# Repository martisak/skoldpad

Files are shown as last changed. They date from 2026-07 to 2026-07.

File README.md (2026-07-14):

<p align="center">
  <picture>
    <source media="(prefers-color-scheme: dark)" srcset="./images/header-white.svg">
    <source media="(prefers-color-scheme: light)" srcset="./images/header-black.svg">
    Sköldpad logo
  </picture>
</p>

A split, columnar-staggered keyboard built around a
[nice!nano](https://nicekeyboards.com/nice-nano/) MCU with a rotary encoder, laid out with
[ergogen](https://github.com/ergogen/ergogen) and routed in KiCad. It's based on/inspired by
[josukey](https://github.com/Narkoleptika/josukey) (MIT licensed), an ergogen-based Corne clone.

Firmware ([ZMK](https://zmk.dev/), with a custom keymap tuned for Swedish input and coding
symbols) lives in its own repo: **[martisak/zmk-config](https://github.com/martisak/zmk-config)**.

## Renders

<p align="center">
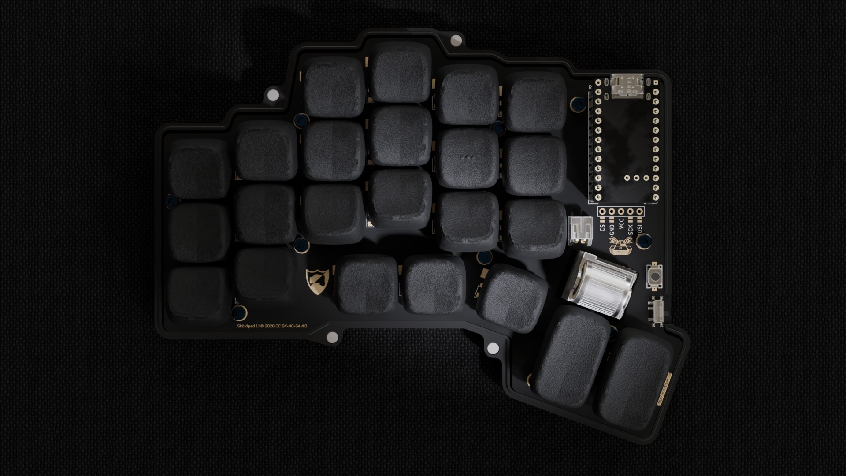
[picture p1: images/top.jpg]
    
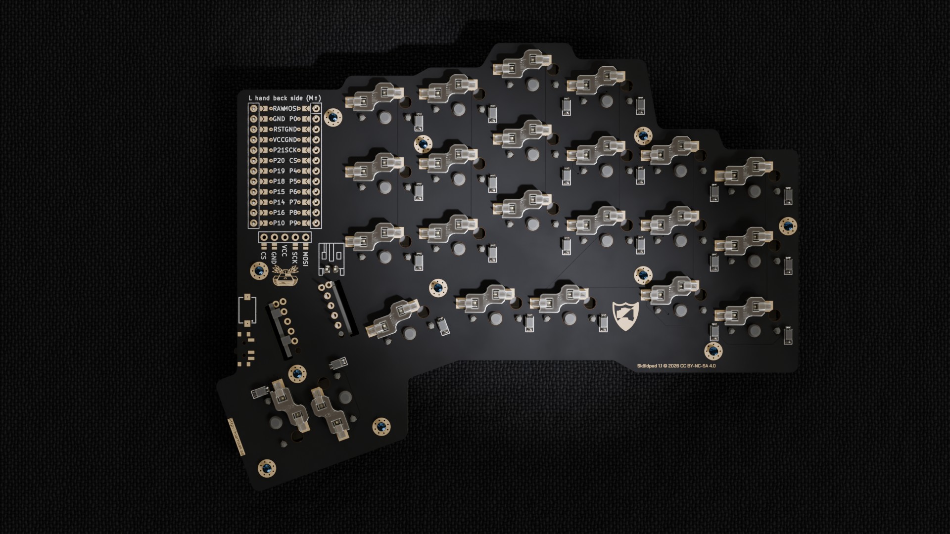
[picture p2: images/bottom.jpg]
    
</p>
<p align="center">
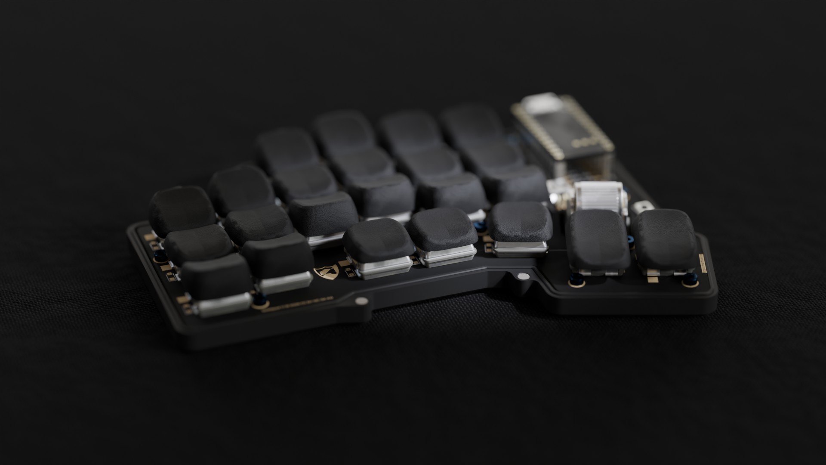
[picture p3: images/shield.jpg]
    
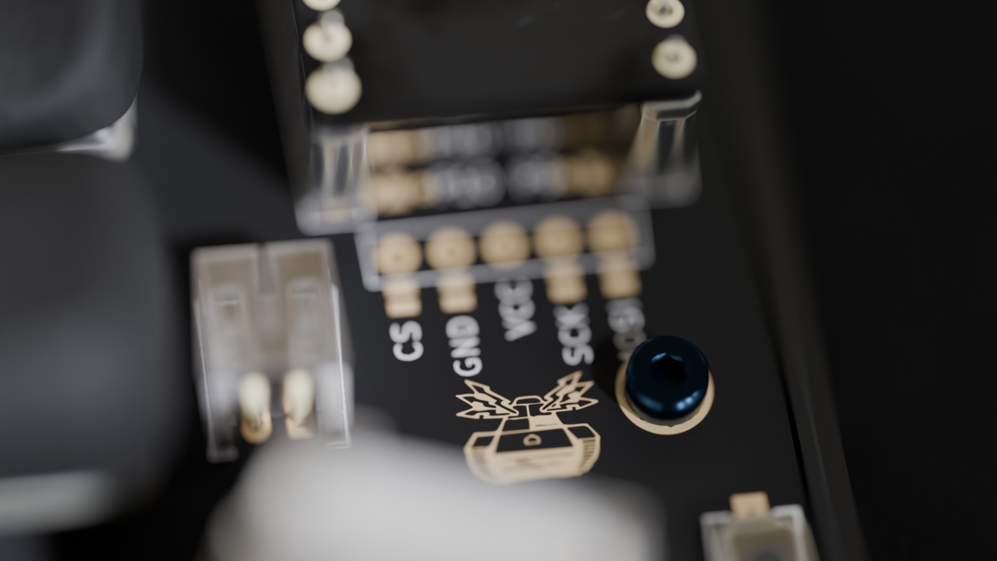
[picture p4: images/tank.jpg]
    
</p>

## Prerequisites

* Node
* KiCad (to open/edit the PCB)

## Getting Started

```bash
git clone https://github.com/martisak/skoldpad.git
cd skoldpad
npm i
```

## Ergogen

The layout lives in `ergogen/config.yaml`.

### Build

Runs Ergogen and builds all of the output files (outlines, case, PCB skeleton) into `ergogen/output`.

```bash
npm run ergogen:build
```

### Watch

Watches `config.yaml` and the `footprints` directory and re-runs the build on changes.

```bash
npm run ergogen:watch
```

## KiCad

The hand-routed PCB lives at [`ergogen/kicad/skoldpad.kicad_pcb`](./ergogen/kicad/skoldpad.kicad_pcb)
(along with the schematic, 3D step model, and the custom `Skoldpad.pretty` footprint library it
depends on) — open `ergogen/kicad/skoldpad.kicad_pro` in KiCad.

<p align="center">
  <picture>
    <source media="(prefers-color-scheme: dark)" srcset="./images/schematic-dark.svg">
    <source media="(prefers-color-scheme: light)" srcset="./images/schematic-light.svg">
    Sköldpad PCB layout
  </picture>
</p>

Regenerate these from the routed board with `make schematics` (requires `kicad-cli` and Python 3
on `PATH`); see the [`Makefile`](./Makefile).

## Firmware

Firmware and keymap are maintained separately at
[martisak/zmk-config](https://github.com/martisak/zmk-config):

```bash
git clone git@github.com:martisak/zmk-config.git
```

It's a [nice!nano](https://nicekeyboards.com/nice-nano/) ZMK build with its own keymap (not
based on Miryoku), tuned for the macOS Swedish layout — base layer plus NUM, FUNC, and
directional layers. Builds run in GitHub Actions on every push; grab the `.uf2` artifacts from
the latest successful run.

The PCB footprints support a [nice!view](https://nicekeyboards.com/nice-view) display — this
should work but hasn't been tested yet.

## Case

<p align="center">
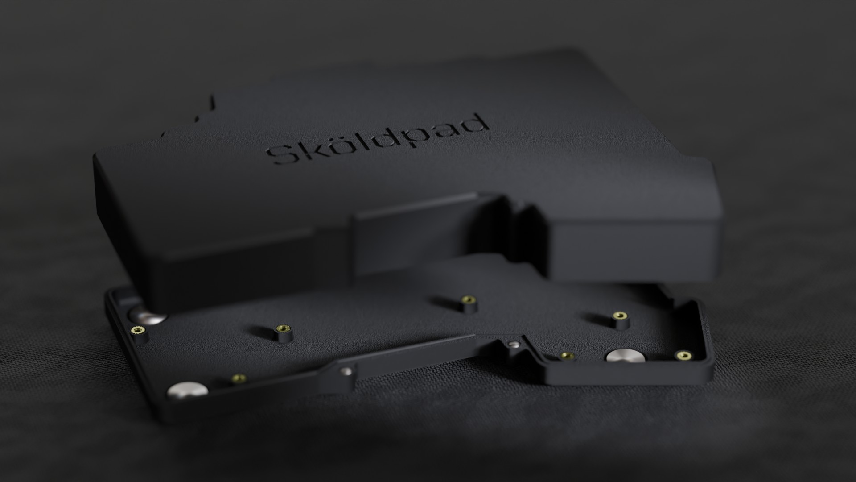
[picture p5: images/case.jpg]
    
</p>

The case is designed in [Shapr3D](https://app.shapr3d.com/p/ba8f4a1e-6f99-4bed-8f1e-6df41bfcee0b)
(viewable in 3D at that link) and 3D printed. STL files for both halves (top and bottom shells)
are in [`case/`](./case):

* [`case/left.stl`](./case/left.stl) / [`case/left_top.stl`](./case/left_top.stl)
* [`case/right.stl`](./case/right.stl) / [`case/right_top.stl`](./case/right_top.stl)

## Bill of Materials

Quantities below are **per half**; this design is one hand's PCB, fabricated twice (one
normal, one mirrored) for a complete pair — double everything for a full two-hand build.

**This PCB is Choc v1 (PG1350) only.** The switch footprint's center hole and stabilizer-leg
positions don't match Choc v2 or MX, so neither is a drop-in substitution — see Future Work.

| Part | Qty/half | Notes |
|---|---:|---|
| [nice!nano](https://nicekeyboards.com/nice-nano/) | 1 | MCU, one per half (each half is an independent BLE unit) |
| [nice!view](https://nicekeyboards.com/nice-view) | 1 | Display — **untested**, see Known Issues; optional |
| Panasonic EVQWGD001 rotary encoder | 1 | ⚠️ Discontinued by Panasonic — check old-stock listings (e.g. [Jotrin](https://www.jotrin.com/product/parts/EVQWGD001)) or plan to substitute a pin-compatible EVQW-series encoder |
| Kailh Choc v1 switch | 23 | See Future Work — v2 is the recommended switch going forward |
| Kailh PG1350 hotswap socket | 23 | Choc v1 hotswap socket, e.g. [Chosfox](https://chosfox.com/products/kailh-choc-switch-1350-hot-swap-sockets) |
| SOD-123W diode (e.g. 1N4148W) | 23 | Standard keyboard-matrix switching diode |
| JST PH 2-pin connector (S2B-PH-K, 2.0mm) | 1 | Battery connector |
| LiPo battery (JST PH 2-pin) | 1 | Capacity not specified by the design — pick to fit the case |
| Kailh PCM12 SPDT slide switch | 1 | Power on/off |
| Würth WS-TASV SMT tactile switch ([434121025816](https://www.digikey.com/en/products/detail/w%C3%BCrth-elektronik/434121025816/5209078)) | 1 | Reset button |
| M2 screws + threaded inserts/standoffs | 11 sets | One per mounting point in `config.yaml` (`screw_*` positions) |
| 1u keycap (Choc profile) | 21 | |
| 1.5u keycap (Choc profile) | 2 | Thumb keys — see Known Issues re: rotation |

Not in the PCB itself but needed to finish a build: the 3D-printed case (see Case section
above) and a filament of your choice.

## Known Issues

* The two thumb keys should be rotated to accept a 1.5u keycap, as shown in the renders.
* nice!view support is untested — should work per the footprint, but not confirmed on hardware.
* The case's screw posts are thin and prone to cracking when installing the threaded inserts
  (see Bill of Materials — M2 screws + threaded inserts/standoffs); consider thickening the
  posts in the Shapr3D model or heat-setting inserts more carefully.

## Future Work

* Move to Choc v2 switches — currently on v1, which has a smaller center post than v2.
* Test compatibility with full-size MX switches.
* Test nice!view once one arrives (currently on order).
* Update the BOM's rotary encoder — the specified Panasonic EVQWGD001 is discontinued;
  find and validate a pin-compatible replacement.
* Consider per-key LEDs instead of underglow — underglow would need a transparent case,
  which the current 3D-printed design isn't.

## License

Code (footprint generator scripts, build tooling) is [MIT](./LICENSE). The
hardware design (PCB, schematic, case, and ergogen layout) is
[CC BY-NC-SA 4.0](./LICENSE-HARDWARE), matching the license of the nice!nano
and nice!view footprints it incorporates (see Thanks below).

## Thanks

* <a href="https://github.com/ergogen/ergogen" target="_blank">Ergogen</a>
* <a href="https://discord.gg/nbKcAZB" target="_blank">Absolem Club Discord</a>
* <a href="https://github.com/infused-kim/kb_ergogen_fp" target="_blank">@infused-kim</a>
  for the original nice!nano and nice!view footprints, and
  <a href="https://github.com/ceoloide/ergogen-footprints" target="_blank">@ceoloide</a>
  for maintaining and upgrading them to KiCad 8 (both CC BY-NC-SA 4.0)
* <a href="https://github.com/tsteffek/Ergogen-V4-Migration-Guide" target="_blank">V4 Migration Guide</a>
* <a href="https://gitlab.com/Audijo/keyboard" target="_blank">Claw</a>
* <a href="https://github.com/MrCarney/mrkeyboard" target="_blank">MrKeyboard</a>
* <a href="https://github.com/foostan/crkbd" target="_blank">Corne keyboard</a>
* <a href="https://www.youtube.com/watch?v=dg2TT1OJlQs" target="_blank">Ben Vallack</a>
* <a href="https://github.com/zmkfirmware/zmk" target="_blank">ZMK</a>
* <a href="https://github.com/Narkoleptika/josukey" target="_blank">josukey</a> — the base this board started from
* <a href="https://sv.wikipedia.org/wiki/V%C3%A4sterg%C3%B6tlands_landskapsvapen" target="_blank">Västergötlands landskapsvapen</a> — inspiration for the logo
* <a href="https://fonts.google.com/specimen/Chakra+Petch" target="_blank">Chakra Petch</a> — typeface used for PCB text and case engraving

## AI Disclosure

Claude (Anthropic) assisted with README and documentation polish — drafting and formatting
text (including the BOM table and general presentation of this repo) from the author's own
notes and decisions. The design, PCB, firmware, fabrication work, and content substance
(including Known Issues and Future Work) are the author's own.

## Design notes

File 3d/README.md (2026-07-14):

# 3D models

Referenced by `(model ...)` entries in `ergogen/kicad/skoldpad.kicad_pcb` via
`${KIPRJMOD}/../../3d/`. Ergogen's footprint generators don't attach these (the
choc switch/socket/keycap models are per-instance overrides added directly in
the board file; `mcu_nice_nano.js` supports a `mcu_3dmodel_filename` param but
it isn't set in `config.yaml`, so this MCU model is also a per-instance override).

| File | Part | Source | License |
|---|---|---|---|
| `SW_Kailh_Choc_V1.stp` | Kailh Choc v1 (PG1350) switch | [kiswitch/kiswitch](https://github.com/kiswitch/kiswitch) | MIT / CC-BY-SA (dual) |
| `SW_Hotswap_Kailh_Choc_v1.stp` | Kailh Choc v1 hotswap socket | [kiswitch/kiswitch](https://github.com/kiswitch/kiswitch) | MIT / CC-BY-SA (dual) |
| `MBK-1u.step` | MBK profile 1u keycap | [namnlos-io/choc_keycaps](https://github.com/namnlos-io/choc_keycaps), MBK folder, by Max Burger | CC BY-NC 4.0 |
| `MBK_Keycap_-_1.5u.step` | MBK profile 1.5u keycap | [namnlos-io/choc_keycaps](https://github.com/namnlos-io/choc_keycaps), MBK folder, by Max Burger | CC BY-NC 4.0 |
| `nice!nano v2.step` | nice!nano v2 MCU | [GrabCAD: nice!nano v2](https://grabcad.com/library/nice-nano-v2-1) | check GrabCAD page for terms before redistributing |

The choc/hotswap/keycap filenames match what the hand-routed board already
referenced (as absolute paths on another machine, `/Users/eisamar/devel/...`)
before this fix — same model family, just relocated under the repo and made
portable via `${KIPRJMOD}`.

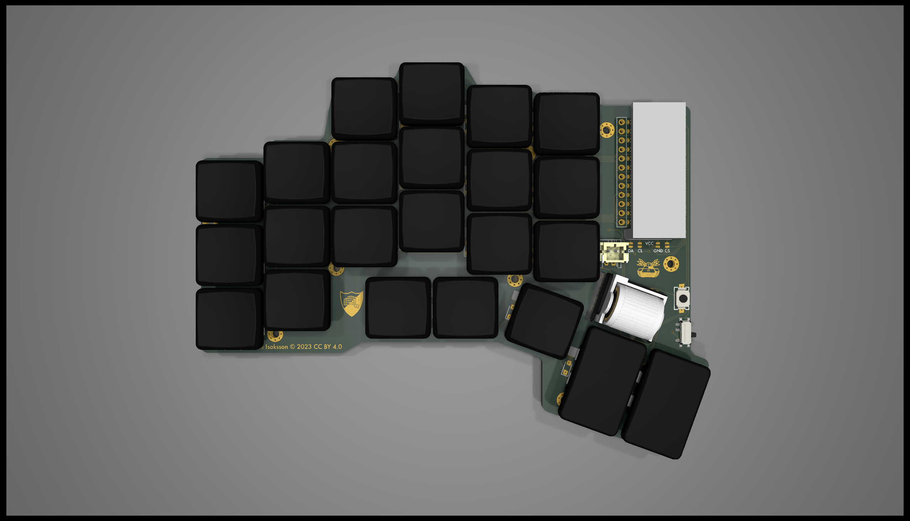
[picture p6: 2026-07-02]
images/top.png

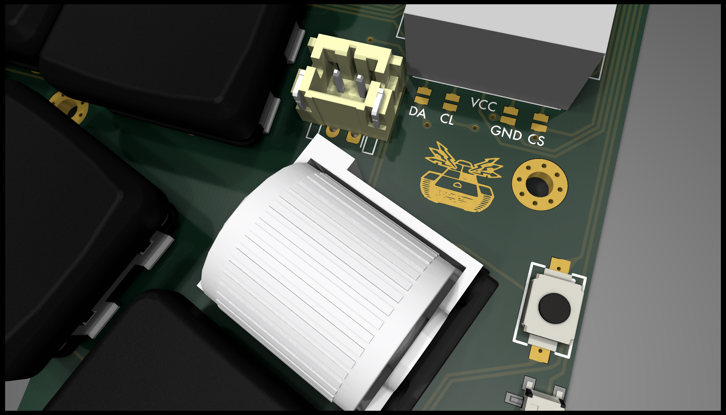
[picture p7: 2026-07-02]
images/tank.png

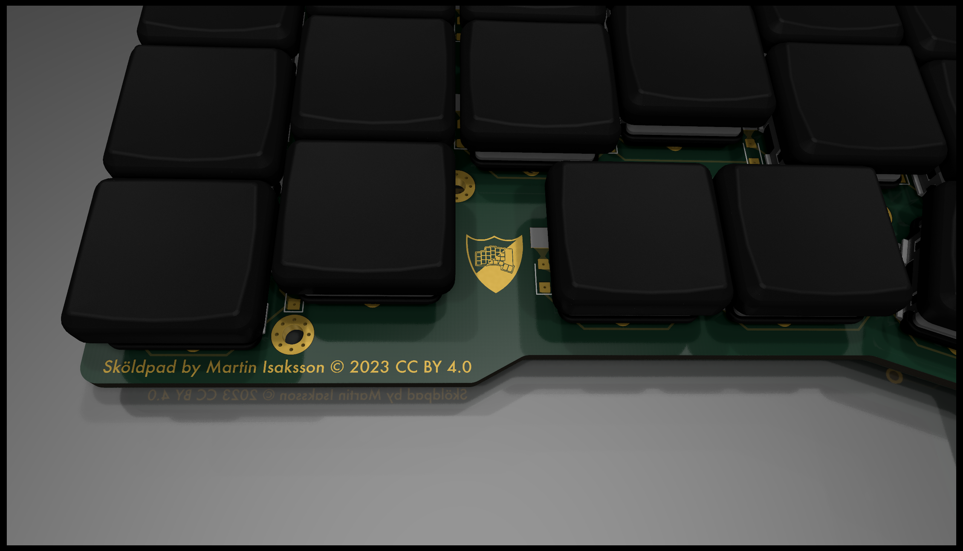
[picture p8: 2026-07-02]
images/shield.png

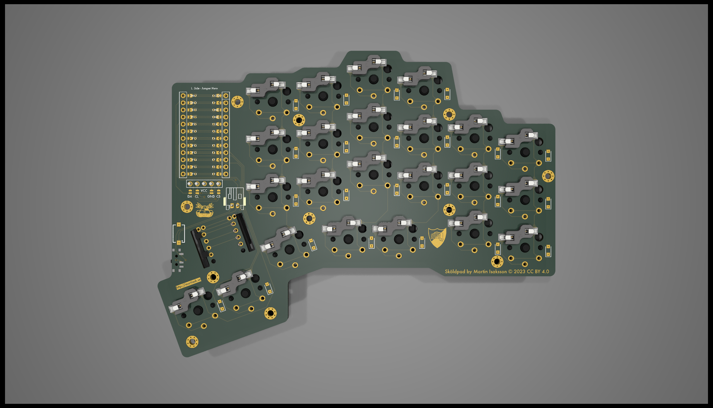
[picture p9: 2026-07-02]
images/bottom.png

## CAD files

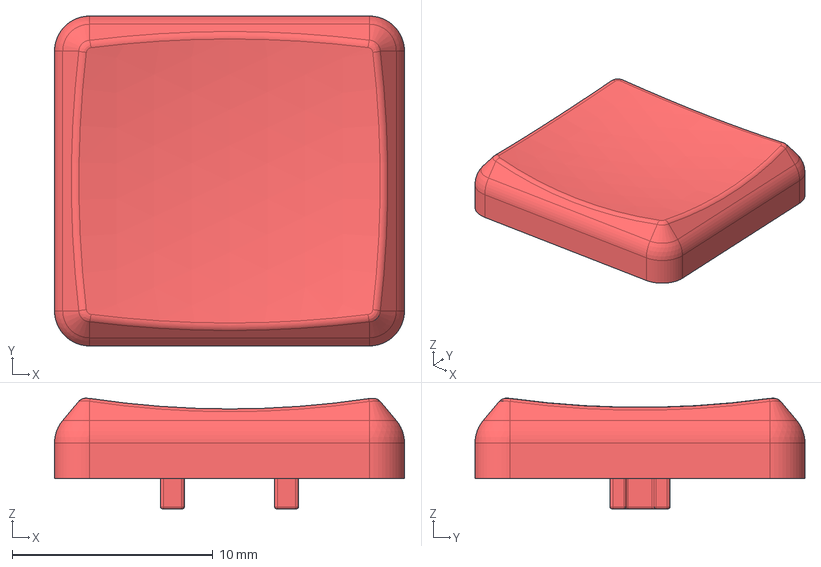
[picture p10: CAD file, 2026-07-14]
3d/MBK-1u.step
17.4 x 16.4 x 5.52 mm

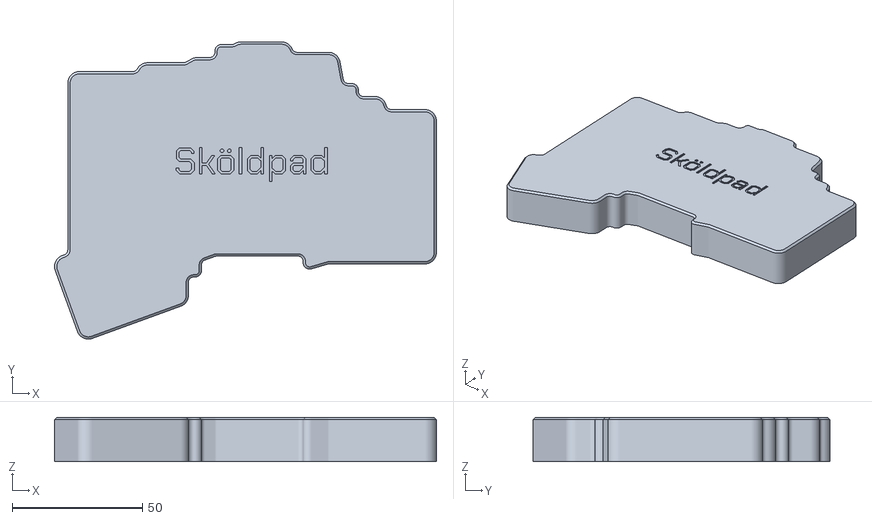
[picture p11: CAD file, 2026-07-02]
case/right_top.stl
146.9 x 114.3 x 17.0

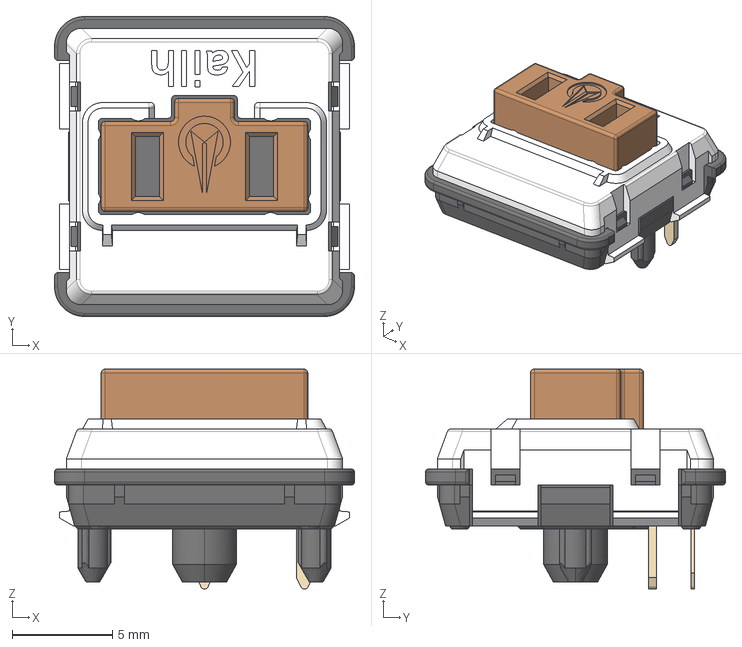
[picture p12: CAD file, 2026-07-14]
3d/SW_Kailh_Choc_V1.stp
15.0 x 15.0 x 11.0 mm

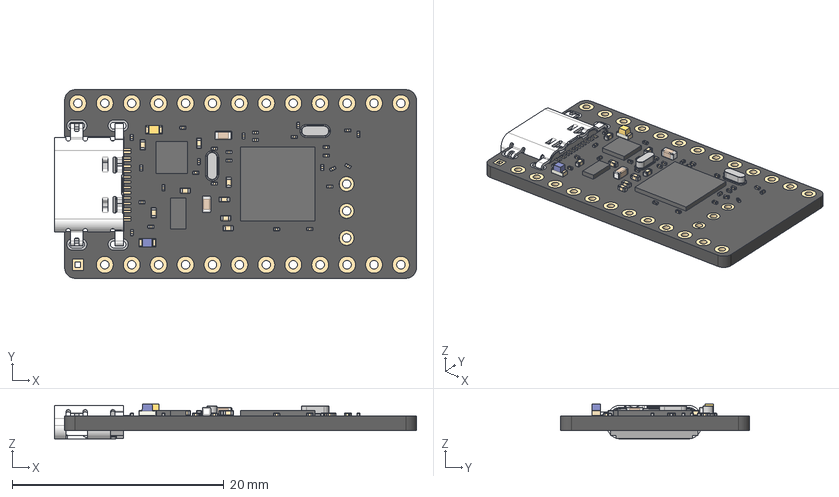
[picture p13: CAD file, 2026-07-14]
3d/nice!nano v2.step
34.2 x 17.8 x 3.28 mm
nice!nano v1.0
SSOP16
LED_0603_1608Metric_ON
LED_0603_1608Metric_ON_1
Crystal Oscillator
Crystal Oscillator_1
usb4520-03-0-a_1
C0201 x 21
C0402 x 8
C0201_1 x 7

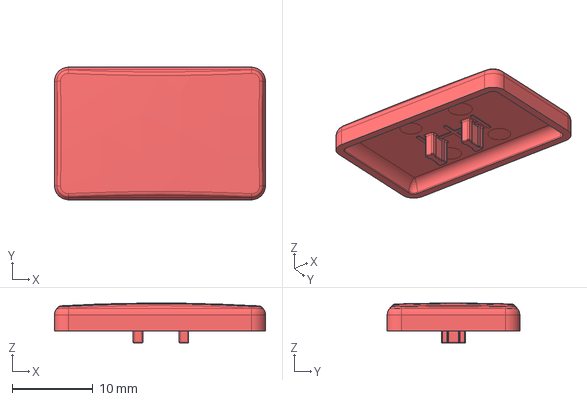
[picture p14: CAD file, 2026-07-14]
3d/MBK_Keycap_-_1.5u.step
26.2 x 16.4 x 4.94 mm

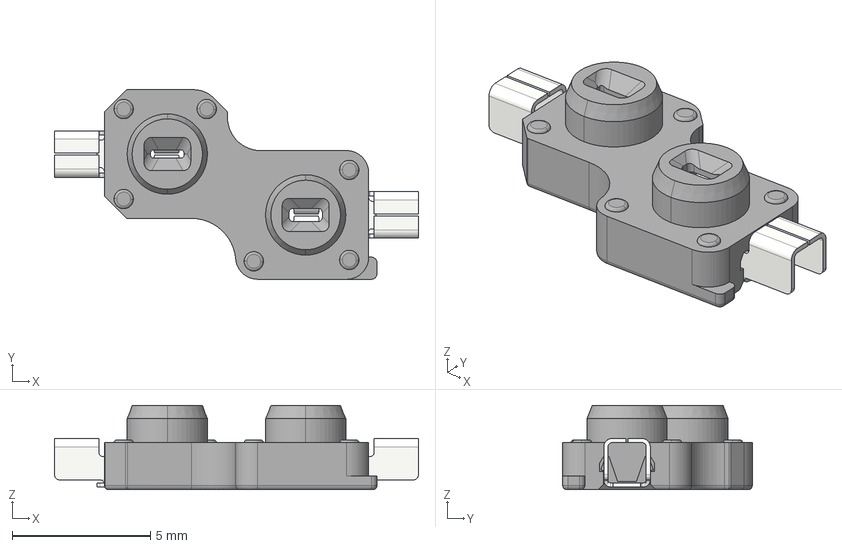
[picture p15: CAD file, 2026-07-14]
3d/SW_Hotswap_Kailh_Choc_v1.stp
13.2 x 6.85 x 3.05 mm

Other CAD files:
case/left_top.stl

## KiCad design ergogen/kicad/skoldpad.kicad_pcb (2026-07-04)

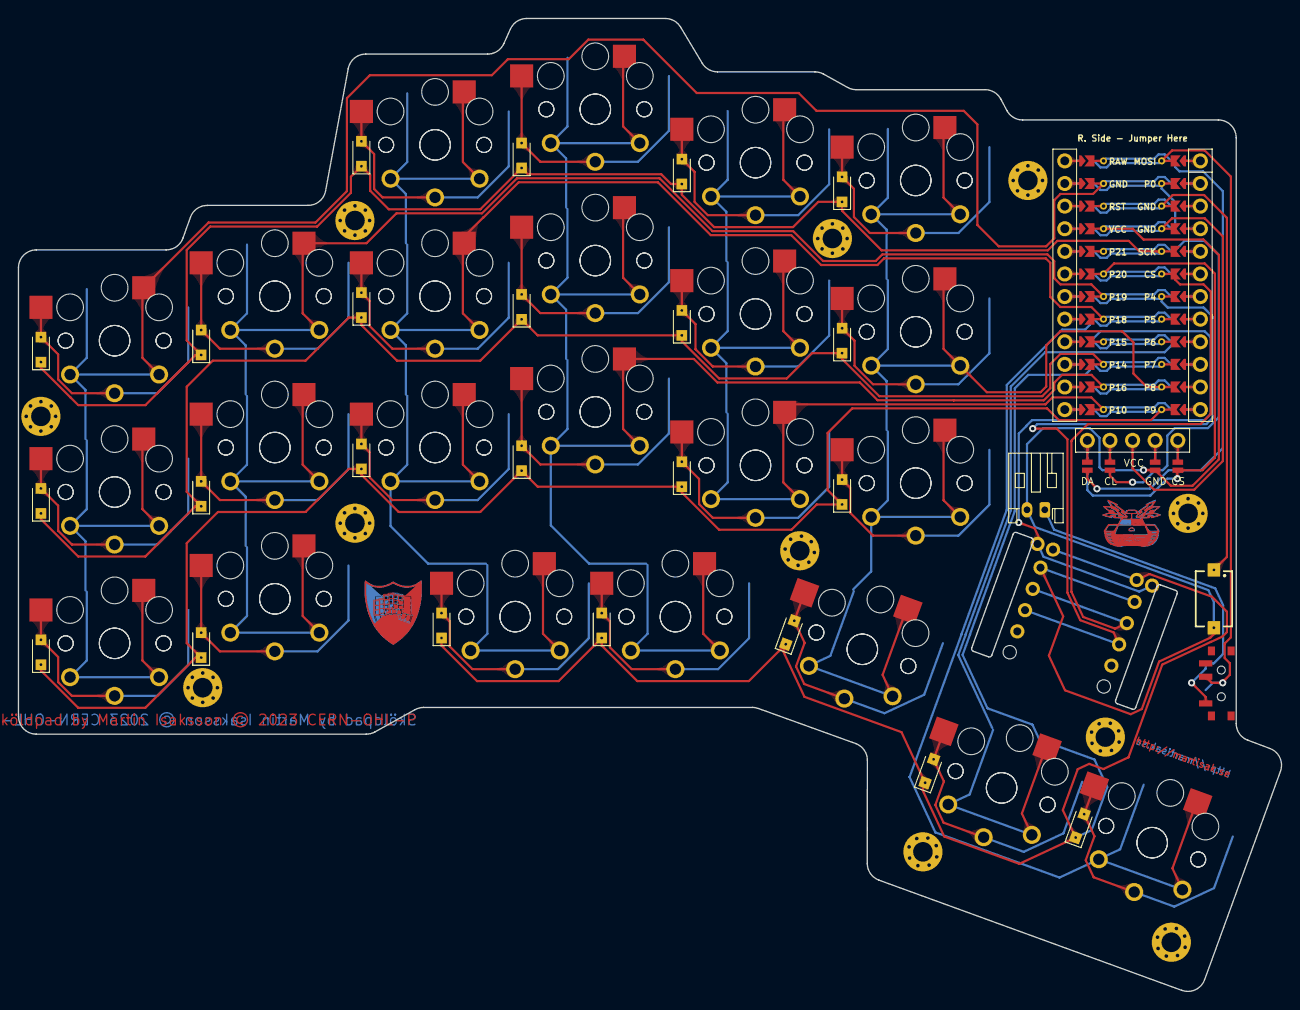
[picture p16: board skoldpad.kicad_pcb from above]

Board: 2 copper layers, 141.9 x 109.3 mm, 85 parts (0 on the bottom side), 47 nets.

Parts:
D1, D2, D3, D4, D5, D6, D7, D8, D9, D10, D11, D12, D13, D14, D15, D16, D17, D18, D19, D20, D21, D22, D23: Nexperia_CFP3_SOD-123W
DISP1: nice!view
H1, H2, H3, H4, H5, H6, H7, H8, H9, H10, H11: MountingHole_2.2mm_M2_Pad_Via
MCU1: nice_nano
S1, S2, S3, S4, S5, S6, S7, S8, S9, S10, S11, S12, S13, S14, S15, S16, S17, S18, S19, S20, S21, S22, S23, S24, S25, S26, S27, S28, S29, S30, S31, S32, S33, S34, S35, S36, S37, S38, S39, S40, S41, S42, S43, S44, S45, S46: PG1350
S48: 434121025816
T1: SW_SPDT_PCM12
_1: JST_PH_S2B-PH-K_1x02_P2.00mm_Horizontal

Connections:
CS: DISP1.13, DISP1.23, MCU1.119
DISP1_1: DISP1.1, DISP1.14, DISP1.27
DISP1_2: DISP1.2, DISP1.15, DISP1.26
DISP1_4: DISP1.4, DISP1.16, DISP1.25
DISP1_5: DISP1.5, DISP1.17, DISP1.24
GND: DISP1.12, DISP1.22, MCU1.2, MCU1.121, MCU1.122, S48.2, _1.2
MOSI: DISP1.10, DISP1.20, MCU1.124
P0: MCU1.123, S1.1, S2.1, S3.1, S24.1, S25.1, S26.1
P4: MCU1.118, S4.1, S5.1, S6.1, S27.1, S28.1, S29.1
P5: MCU1.117, S7.1, S8.1, S9.1, S19.1, S30.1, S31.1, S32.1, S42.1
P6: MCU1.116, S22.1, S45.1
P7: D2.1, D5.1, D8.1, D11.1, D19.1, D22.1, MCU1.115
P8: MCU1.114, S10.1, S11.1, S12.1, S20.1, S33.1, S34.1, S35.1, S43.1
P9: MCU1.113, S13.1, S14.1, S15.1, S36.1, S37.1, S38.1
P10: D1.1, D4.1, D7.1, D10.1, D18.1, D21.1, MCU1.12
P14: D13.1, D14.1, D15.1, D16.1, D17.1, MCU1.10
P16: MCU1.11, S16.1, S17.1, S18.1, S21.1, S39.1, S40.1, S41.1, S44.1
P18: MCU1.8, S23.1, S46.1
P21: D3.1, D6.1, D9.1, D12.1, D20.1, D23.1, MCU1.5
RAW: MCU1.1, T1.2
RST: MCU1.3, S48.1
SCK: DISP1.11, DISP1.21, MCU1.120
VCC: DISP1.3, MCU1.4
control_farinner_home: D13.2, S19.2, S42.2
control_home_home: D15.2, S21.2, S44.2
control_inner_home: D14.2, S20.2, S43.2
main_index_bottom: D7.2, S13.2, S36.2
main_index_home: D8.2, S14.2, S37.2
main_index_top: D9.2, S15.2, S38.2
main_inner_bottom: D10.2, S16.2, S39.2
main_inner_home: D11.2, S17.2, S40.2
main_inner_top: D12.2, S18.2, S41.2
main_middle_bottom: D21.2, S10.2, S33.2
main_middle_home: D22.2, S11.2, S34.2
main_middle_top: D23.2, S12.2, S35.2
main_outer_bottom: D1.2, S1.2, S24.2
main_outer_home: D2.2, S2.2, S25.2
main_outer_top: D3.2, S3.2, S26.2
main_pinky_bottom: D18.2, S4.2, S27.2
main_pinky_home: D19.2, S5.2, S28.2
main_pinky_top: D20.2, S6.2, S29.2
main_ring_bottom: D4.2, S7.2, S30.2
main_ring_home: D5.2, S8.2, S31.2
main_ring_top: D6.2, S9.2, S32.2
pos: T1.1, _1.1
thumb_middle_home: D16.2, S22.2, S45.2
thumb_outer_home: D17.2, S23.2, S46.2

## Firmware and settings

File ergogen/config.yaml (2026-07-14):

meta:
  engine: 4.0.2
  name: Sköldpad
  version: 1.1
  author: martisak
  url: https://github.com/martisak/skoldpad
units:
  kx: cx
  ky: cy
  px: 2
  py: 2

  # Double Padding Variables
  dkx: kx + 4
  dky: ky + 4
  mcu_height: 34
  mcu_width: 18
  
  # M2 Screw Inserts
  screwSize: 1.5
  standoffSize: 2.5

  # distance keys to mcu
  mcu_padding: 1.5
points:
    key.padding: ky
    zones:
        main:
            anchor:
                shift: [5kx,-7ky]
            rows:
                bottom.row_net: P10
                home.row_net: P7
                top.row_net: P21
            columns:
                outer:
                    key:
                        col_net: P0
                        spread: kx
                        tags: normal

                pinky:
                    key:
                        stagger: 5
                        col_net: P4
                        spread: kx
                        tags: 
                          - diodeshiftdown
                ring:
                    key:
                        col_net: P5
                        stagger: ky
                        spread: kx
                        tags: normal
                middle:
                    key:
                        col_net: P8
                        stagger: 4
                        spread: kx
                        tags: diodeshiftdown
                index:
                    key:
                        col_net: P9
                        stagger: -6
                        spread: kx
                        tags: normal
                inner:
                    key:
                        col_net: P16
                        stagger: -2
                        spread: kx
                        tags: normal

        control:
            anchor:
                ref: main_index_bottom
                shift: [-1.5kx, -1ky]
            rows.home.row_net: P14
            columns:
                farinner.key:
                    col_net: P4
                    spread: kx
                    tags: normal
                inner.key:
                    col_net: P5
                    spread: kx
                    tags: normal
                home.key:
                    col_net: P8
                    spread: kx + 1.5px
                    shift: [0, -0.0275ky] 
                    rotate: -20
                    stagger: -3.2
                    tags: normal
        thumb:
            anchor:
               ref: main_index_bottom
               shift: [1.65kx, -1.8ky] 
               rotate: -20
            rows.home.row_net: P14
            columns:
                middle.key:
                    col_net: P9
                    spread: kx
                    width: 1.5u
                    rotate: -90
                    tags: 
                        - key1_5u 
                        - normal
                    stagger: -6
                outer.key:
                    col_net: P16
                    spread: kx
                    width: 1.5u
                    rotate: -90
                    tags: 
                        - key1_5u
                        - normal
        mcu:
          anchor:
            ref: main_inner_top
          key:
            tags: [mcu]
            width: mcu_height  # footprint width/height unintuitive
            height: mcu_width
            rotate: -90
            shift: [mcu_padding+1.27kx, -mcu_width/2-mcu_padding]
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

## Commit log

2026-07-02 Rebrand as Sköldpad 1.0, fold in current PCB, drop stale ZMK config
    - Rename ergogen pcbs.martin key to pcbs.skoldpad
    - Fold in the hand-routed PCB, schematic, step model, and custom
    Signature footprint library from the working KiCad project, with a
    project-local fp-lib-table so it opens cleanly on a fresh clone
    - Add board renders and the v1 build photo to the README
    - Remove the zmk/ directory; firmware now lives in martisak/zmk-config
    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
    [josukey.kicad_pcb, skoldpad.kicad_sch]
2026-07-02 Remove josukey-era images, keep own renders
    v1.jpg and josukey.png are from the original josukey build, not this
    board; the top/bottom/shield/tank renders are Sköldpad's own.
2026-07-02 Add case render to README
    3D rendering of the 3D-printed case (without the keyboard installed).
2026-07-02 Add PCB layout render to README
    Cropped the white plot border out; also normalized the filename to
    ASCII (schematic.png) to match the other image names in this repo.
2026-07-02 Split hardware/software licensing, remove unused footprints
    Code stays MIT; the hardware design (PCB, schematic, case, ergogen
    layout) is now CC BY 4.0 under LICENSE-HARDWARE. Also drops the unused
    love/peace footprints and images, leftover from the josukey template
    and not referenced by config.yaml.
2026-07-02 Clarify MCU and correct nice!view status
    Link to nice!nano as the actual MCU used. nice!view support is
    untested (should work per the footprint, but not confirmed on
    hardware), so drop the confident claim and add it to Known Issues.
2026-07-02 Add case STL files
    Both halves, top and bottom shells, exported from the Shapr3D design.
    Link them from the README's Case section.
    [left_top.stl, right_top.stl]
2026-07-02 Add Future Work section
    Notes for the next revision: Choc v2 switches (currently on v1), test
    full-size MX compatibility, test nice!view once it arrives, and look
    into CERN-OHL as a hardware-specific license alternative to CC BY 4.0.
2026-07-02 Switch hardware license from CC BY 4.0 to CERN-OHL-P v2
    CERN-OHL is purpose-built for hardware (patent grant/estoppel,
    manufactured-product provisions) where CC BY is a copyright license
    for creative works. CERN-OHL-P is the permissive variant, matching
    the same "credit me, do what you want" intent CC BY 4.0 had here.
    Also updates the PCB silkscreen text (front/back Cu and Mask layers)
    and title block comment, which still read "CC BY 4.0" — dropped the
    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
2026-07-02 Document PCB-only license text, drop stale footprint backup
    - Note in config.yaml that the hand-added license credit line on the
    PCB isn't sourced from ergogen and won't survive a regeneration.
    - Remove text.js.old, a leftover pre-rewrite copy of text.js that
    ergogen never loads.
    [config.yaml]
2026-07-02 Link Shapr3D case model in README
    Publicly viewable 3D model, while the native/STEP source is still
    pending export (Shapr3D license lapsed).
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2026-07-02 Add BOM, remove unused footprints, note EVQWGD001/LED ideas
    - New Bill of Materials section: parts, per-half quantities, and
    sourcing links, derived directly from the compiled PCB's footprint
    list (23 keys, 1 each of MCU/display/encoder/battery connector/power
    switch/reset switch, 11 mounting points).
    - Removed 14 footprint files never referenced by config.yaml: 12 .js
    generators (hole, jumper, keepout, martin, nice-view, niceview,
    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
2026-07-03 Note thin case screw posts crack risk in Known Issues
2026-07-03 Bump to 1.1, switch to Chakra Petch, add theme-aware logo
    - Unify PCB text on Chakra Petch Medium (was Futura, plus a stale
    Chakra Petch SemiBold default); credit Chakra Petch in Thanks
    - Generate the board credit/license line from ergogen instead of
    hand-editing the routed PCB (was undocumented drift risk)
    - Replace static logo.png with a theme-aware SVG header (light/dark)
    - Align version to 1.1 across package.json, ergogen meta, and the
    PCB credit text; fix missing "ö" in ergogen meta.name
    - Add npm run lint:spelling to catch future ASCII "Skoldpad" typos
    - Add CLAUDE.md for future Claude Code sessions in this repo
    [config.yaml]
2026-07-03 Fold credit/license text into owner footprint, drop off-board duplicate
    The separate credit/credit_back footprints (added at thumb_outer_home)
    were running off the board edge. Move the credit text into the
    existing owner/owner_back footprints instead, which were already
    known to sit on-board, and shrink the font to fit the longer string.
2026-07-03 Shorten owner text and rename to license, note Choc v1-only in BOM
    [config.yaml]
2026-07-03 Replace mislabeled PCB screenshot with generated dark/light layout art
    schematic.png was actually a flat PCB layout render (the project has no
    real eeschema schematic capture). Regenerate it via kicad-cli as a themed
    SVG pair matching the header logo's dark/light picture-switch, and add a
    Makefile target (`make schematics`) to reproduce them from the routed
    board. Also fixes 70 silkscreen text objects still requesting the
    unavailable "Futura" font instead of the project's actual Chakra Petch.
    [skoldpad.kicad_pcb]
2026-07-04 Rename Signature.pretty footprint library to Skoldpad.pretty
    More project-specific name for the custom footprint library, updated
    in fp-lib-table, the routed PCB, CLAUDE.md, and README.
    [skoldpad.kicad_pcb]
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2026-07-14 Migrate to ergogen 4.2.1 and KiCad 8 output
    Bump ergogen 4.0.2 -> 4.2.1 and set template: kicad8 in the config.
    Update jst-s2b-ph-kl, mountinghole, pcm12, sod-123w, text and
    wuerth-434121025816 footprints to the KiCad 8 / ergogen 4.2 syntax,
    and add modernized choc/scrollwheel footprints with byte-identical
    geometry. Includes the KiCad version bump in skoldpad.kicad_prl.
2026-07-14 Relicense hardware to CC BY-NC-SA 4.0, swap nice!nano/nice!view footprints
    Replace CERN-OHL-P v2 with CC BY-NC-SA 4.0 in LICENSE-HARDWARE and in
    the on-board license silkscreen text. Replace nice_nano_pretty and
    nice_view footprints with mcu_nice_nano and display_nice_view, updating
    the promicro/niceview config entries to the new reversible params.
    Update CLAUDE.md accordingly.
    [config.yaml]
2026-07-14 Add shield and tank silkscreen footprints
    Add shield and tank artwork footprints with front/back placements in
    the config, the corresponding Skoldpad.pretty modules, and the source
    SVGs.
2026-07-14 Add 3D reference models for switches, keycaps and nice!nano
    STEP models for Kailh Choc v1 (plain and hotswap), MBK 1u/1.5u keycaps
    and the nice!nano v2, with a README noting their sources.
    [MBK-1u.step, MBK_Keycap_-_1.5u.step, SW_Hotswap_Kailh_Choc_v1.stp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]
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2026-07-15 :sparkles: Add custom KiCad footprints for Skoldpad.pretty library
    12 hand-authored footprints referenced via fp-lib-table: Choc PG1350
    variants (rows, thumb, homing, tilted), mounting hole, diode, and shield.
    AI-Contribution: Claude Opus 4.8 staged and committed pre-existing footprint files
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2026-07-15 :sparkles: Regenerate shield footprint at finer curve precision
    Default svg2mod precision (20) flattened the rounded curves into
    visible facets on the smaller re-exported artwork; -p 0.1 keeps
    curve deviation under 0.1mm instead.

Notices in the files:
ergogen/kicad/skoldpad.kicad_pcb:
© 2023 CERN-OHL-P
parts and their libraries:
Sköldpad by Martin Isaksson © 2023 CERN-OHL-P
